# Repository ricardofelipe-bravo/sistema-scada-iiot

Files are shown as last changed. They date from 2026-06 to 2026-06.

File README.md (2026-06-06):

# Sistema SCADA con Nodo Edge IIoT — Monitor de Variables Eléctricas

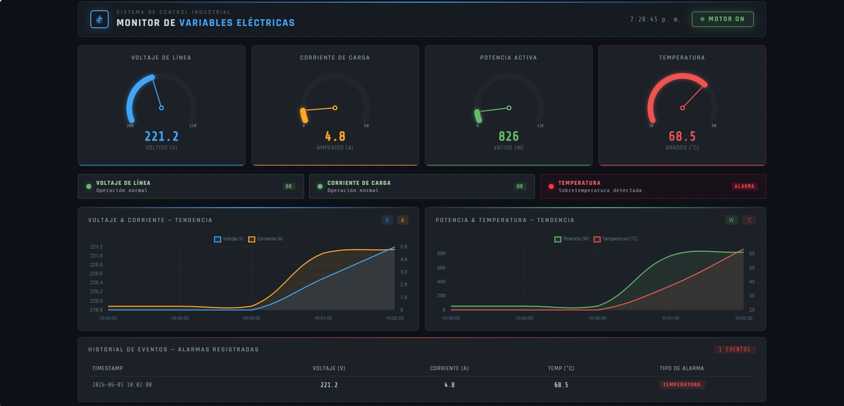
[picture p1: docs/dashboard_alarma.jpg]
Dashboard Alarma


Sistema de monitoreo industrial en tiempo real que integra un nodo Edge basado en **ESP32**, comunicación segura **MQTT/TLS**, protocolo industrial **Modbus TCP** y un dashboard **SCADA web** desarrollado con Python y Flask. Diseñado para supervisión de variables eléctricas en motores industriales con detección automática de alarmas y notificaciones por email.

---

## Arquitectura del Sistema

```
ESP32 (Nodo Edge)
  │  WiFi + Portal Cautivo
  │  MQTT/TLS — HiveMQ Cloud (puerto 8883)
  ▼
Python — monitor.py
  │  Suscriptor MQTT
  ├── SQLite (histórico de mediciones)
  ├── Alertas Email (SMTP — flanco ascendente)
  └── Flask — app.py
          │  API REST
          ▼
    Dashboard Web
    Chart.js — tiempo real
    Gauges + Gráficas + Historial de alarmas
```

---

## Características

- **Nodo Edge ESP32** con portal cautivo para configuración WiFi sin reprogramar, sincronización horaria NTP y LEDs indicadores de estado
- **Dos versiones de firmware** — producción con sensor PZEM-004T y simulación para pruebas sin hardware
- **Comunicación MQTT/TLS** sobre HiveMQ Cloud con publicación de JSON estructurado cada 2 segundos
- **Dashboard SCADA web** con gauges estilo velocímetro, gráficas de tendencia en tiempo real, panel de alarmas y historial de eventos
- **Base de datos SQLite** para almacenamiento histórico de mediciones
- **Sistema de alarmas** con detección por flanco ascendente y notificación automática por email
- **PCB diseñada en KiCad 8** para integración con sensor PZEM-004T
- Arquitectura preparada para conexión con **PLC vía Modbus TCP**

---

## Firmware ESP32 — Dos Versiones

### `nodo_edge_iiot_sensor.ino` — Producción (con PZEM-004T)
Versión para uso con hardware real. Lee voltaje, corriente, potencia activa, energía acumulada, frecuencia y factor de potencia directamente del sensor PZEM-004T. Detecta automáticamente si el sensor no responde.

### `nodo_edge_iiot_simulacion.ino` — Simulación (sin sensor)
Versión para pruebas del sistema completo sin hardware de medición. Simula un motor industrial 1HP / 220V con comportamiento realista — arranque, carga nominal, calentamiento gradual y generación de alarmas.

---

## Portal Cautivo — Configuración WiFi

El ESP32 incluye un portal cautivo que permite configurar la red WiFi sin necesidad de reprogramar el dispositivo.

### Cómo funciona

**Primera vez (sin credenciales guardadas):**

1. El ESP32 enciende y no encuentra red WiFi configurada
2. Crea automáticamente una red WiFi propia:
   - **Red:** `NodoEdge_Config`
   - **Contraseña:** `nodo1234`
3. Conéctate a esa red desde tu celular o computador
4. Se abre automáticamente una página de configuración en `192.168.4.1`
5. Selecciona tu red WiFi e ingresa la contraseña
6. El ESP32 guarda las credenciales y se conecta

**Siguiente encendido:**
- El ESP32 se conecta automáticamente sin mostrar el portal

**Si necesitas cambiar la red:**
- Mantén presionado el botón RESET por 10 segundos para borrar credenciales
- El portal cautivo se activa de nuevo

### Indicadores LED durante el portal
| LED | Estado | Significado |
|---|---|---|
| WiFi (GPIO23) | Parpadeo rápido | Portal cautivo activo |
| WiFi (GPIO23) | Fijo encendido | WiFi conectado |
| MQTT (GPIO22) | Fijo encendido | HiveMQ conectado |
| Alarma (GPIO21) | Fijo encendido | Variable fuera de rango |

---

## Conexión PZEM-004T al ESP32

```
PZEM-004T          ESP32 DevKit 38 pines
─────────          ──────────────────────
VCC (5V)    →      VIN  (pin 19)
GND         →      GND  (pin 14)
TX          →      GPIO16 / RX2  (pin 28)
RX          →      GPIO17 / TX2  (pin 29)
```

> **Importante:** El PZEM-004T trabaja con 220V en su lado de medición. Maneja las conexiones de alta tensión con precaución.

---

## Variables Monitoreadas

| Variable | Unidad | Rango normal | Umbral de alarma |
|---|---|---|---|
| Voltaje de línea | V | 200 – 240 | > 228 V |
| Corriente de carga | A | 0 – 6 | > 5 A |
| Potencia activa | W | calculada | — |
| Factor de potencia | — | 0.75 – 0.95 | — |
| Temperatura | °C | 25 – 65 | > 65 °C |
| Energía acumulada | kWh | — | — |
| Frecuencia | Hz | 59 – 61 | — |

---

## Stack Tecnológico

### Firmware ESP32
| Librería | Autor | Función |
|---|---|---|
| WiFiManager | tzapu | Portal cautivo para configuración WiFi |
| PubSubClient | Nick O'Leary | Cliente MQTT |
| ArduinoJson | Benoit Blanchon | Serialización JSON |
| PZEM004Tv30 | Jakub Mandula | Lectura sensor PZEM-004T |
| WiFiClientSecure | ESP32 built-in | Conexión TLS/SSL |
| time.h | ESP32 built-in | Sincronización NTP |

### Backend Python
| Librería | Función |
|---|---|
| paho-mqtt | Suscripción al broker MQTT |
| flask | Servidor web y API REST |
| sqlite3 | Base de datos histórica |
| smtplib | Envío de alertas por email |

### Frontend
| Tecnología | Función |
|---|---|
| Chart.js | Gráficas de tendencia en tiempo real |
| HTML/CSS/JS | Dashboard SCADA responsivo |
| SVG | Gauges estilo velocímetro animados |

---

## Estructura del Proyecto

```
sistema-scada-iiot/
│
├── monitor.py                          # Suscriptor MQTT + SQLite + alertas email
├── app.py                              # Servidor Flask + API REST
├── .gitignore
│
├── templates/
│   └── index.html                      # Dashboard SCADA
│
├── static/
│   └── chart.js                        # Librería Chart.js (local)
│
├── nodo_edge_iiot.ino/
│   ├── nodo_edge_iiot_sensor.ino       # Firmware producción (PZEM-004T)
│   └── nodo_edge_iiot_simulacion.ino   # Firmware simulación (pruebas)
│
├── pcb/
│   ├── nodo edge IIot.kicad_sch        # Esquemático
│   ├── nodo edge IIot.kicad_pcb        # Layout PCB
│   └── nodo edge IIot.kicad_pro        # Proyecto KiCad
│
└── docs/
    ├── dashboard_motor_off.jpg         # Dashboard — motor apagado
    ├── dashboard_motor_on.jpg          # Dashboard — motor encendido
    └── dashboard_alarma.jpg            # Dashboard — alarma activa
```

---

## Cómo Correr el Proyecto

### Requisitos Python
```bash
pip install flask paho-mqtt
```

### 1. Iniciar el monitor MQTT
```bash
python monitor.py
```

### 2. Iniciar el servidor web
```bash
python app.py
```

### 3. Abrir el dashboard
```
http://127.0.0.1:5000
```

### 4. Publicar datos de prueba desde HiveMQ
Topic: `industrial/motor/variables`

**Motor apagado:**
```json
{"voltaje":219.8,"corriente":0.3,"potencia":55.2,"factor_potencia":0.92,"temperatura":25.0,"estado_motor":0,"timestamp":"2026-06-05 10:00:00"}
```

**Motor encendido:**
```json
{"voltaje":220.5,"corriente":4.5,"potencia":773.6,"factor_potencia":0.78,"temperatura":42.3,"estado_motor":1,"timestamp":"2026-06-05 10:01:00"}
```

**Alarma de temperatura:**
```json
{"voltaje":221.2,"corriente":4.8,"potencia":826.4,"factor_potencia":0.78,"temperatura":68.5,"estado_motor":1,"timestamp":"2026-06-05 10:02:00"}
```

---

---

## Configuración HiveMQ Cloud

HiveMQ Cloud es el broker MQTT que recibe los datos del ESP32 y los entrega a Python.

### Crear cuenta y cluster gratuito

1. Ve a [console.hivemq.cloud](https://console.hivemq.cloud)
2. Crea una cuenta gratuita
3. Click en **"Create new cluster"** → selecciona plan **Free**
4. Elige la región más cercana (US East o EU)
5. Espera que el cluster esté activo (~1 minuto)

### Crear credenciales de acceso

1. Dentro del cluster ve a **"Access Management"**
2. Click en **"Add new credentials"**
3. Crea un usuario y contraseña — guárdalos
4. Permiso: **Publicar y Suscribirse**
5. Click en **Guardar**

### Datos de conexión

Una vez creado el cluster, en la página principal encuentras:

| Parámetro | Dónde encontrarlo | Ejemplo |
|---|---|---|
| Host | Página principal del cluster | `xxxx.s1.eu.hivemq.cloud` |
| Puerto TLS | Siempre es 8883 | `8883` |
| Usuario | Access Management | el que creaste |
| Contraseña | Access Management | la que creaste |

### Actualizar credenciales en el firmware

En el archivo `.ino` busca estas líneas y reemplaza con tus datos:

```cpp
const char* MQTT_HOST = "TU_HOST.s1.eu.hivemq.cloud";
const char* MQTT_USER = "tu_usuario";
const char* MQTT_PASS = "tu_contraseña";
```

### Actualizar credenciales en Python

En `monitor.py` busca:

```python
MQTT_HOST = "TU_HOST.s1.eu.hivemq.cloud"
MQTT_USER = "tu_usuario"
MQTT_PASS = "tu_contraseña"
```

### Probar la conexión desde el cliente web

1. En tu consola HiveMQ ve a la pestaña **"Cliente web"**
2. Conecta con tus credenciales
3. Publica un JSON al topic `industrial/motor/variables`
4. Verifica que `monitor.py` lo recibe en la terminal

---

## PCB — Nodo Edge IIoT

Diseñada en **KiCad 8** para montaje del nodo de medición de variables eléctricas.

### Componentes

| Componente | Referencia | Función |
|---|---|---|
| ESP32 DevKit 38 pines | U1 | Controlador principal |
| PZEM-004T | J1 | Sensor de variables eléctricas |
| LED verde | D1 | Indicador WiFi (GPIO23) |
| LED azul | D2 | Indicador MQTT (GPIO22) |
| LED rojo | D3 | Indicador Alarma (GPIO21) |
| Resistencias 330Ω | R1, R2, R3 | Limitación corriente LEDs |
| Condensador 100µF | C1 | Filtrado alimentación |
| Condensador 100nF | C2 | Desacople alta frecuencia |
| DC Jack 5V | J2 | Entrada de alimentación |

### Alimentación

```
Adaptador 5V DC
      │
   DC Jack
      │
   ESP32 VIN (pin 19) ──── PZEM-004T VCC
      │
   ESP32 interno 3.3V ──── lógica interna
```

### Archivos KiCad en carpeta `pcb/`

| Archivo | Contenido |
|---|---|
| `.kicad_sch` | Esquemático completo con conexiones |
| `.kicad_pcb` | Layout de la PCB con ruteo |
| `.kicad_pro` | Proyecto KiCad con configuración |

> Los archivos pueden abrirse directamente con **KiCad 8.0** disponible en [kicad.org](https://www.kicad.org)

## Capturas del Dashboard

### Motor apagado — operación normal
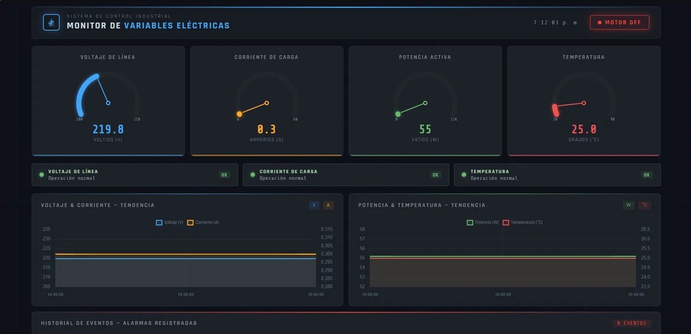
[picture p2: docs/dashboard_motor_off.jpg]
Motor OFF


### Motor encendido — carga nominal
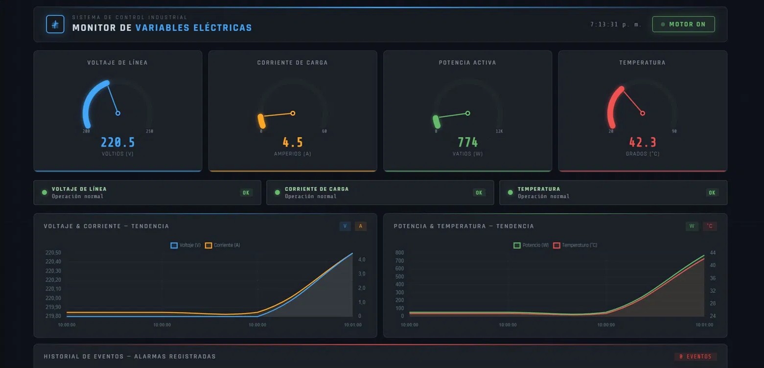
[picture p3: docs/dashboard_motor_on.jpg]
Motor ON


### Alarma activa — sobretemperatura
Alarma

---

## Autor

**Ricardo Felipe Bravo**  
Ingeniero Electrónico — Universidad de Nariño  
Orientado al sector eléctrico e industrial

📩 ricardofelipebravo12@gmail.com  
🔗 [LinkedIn](https://www.linkedin.com/in/ricardofelipe-bravo)

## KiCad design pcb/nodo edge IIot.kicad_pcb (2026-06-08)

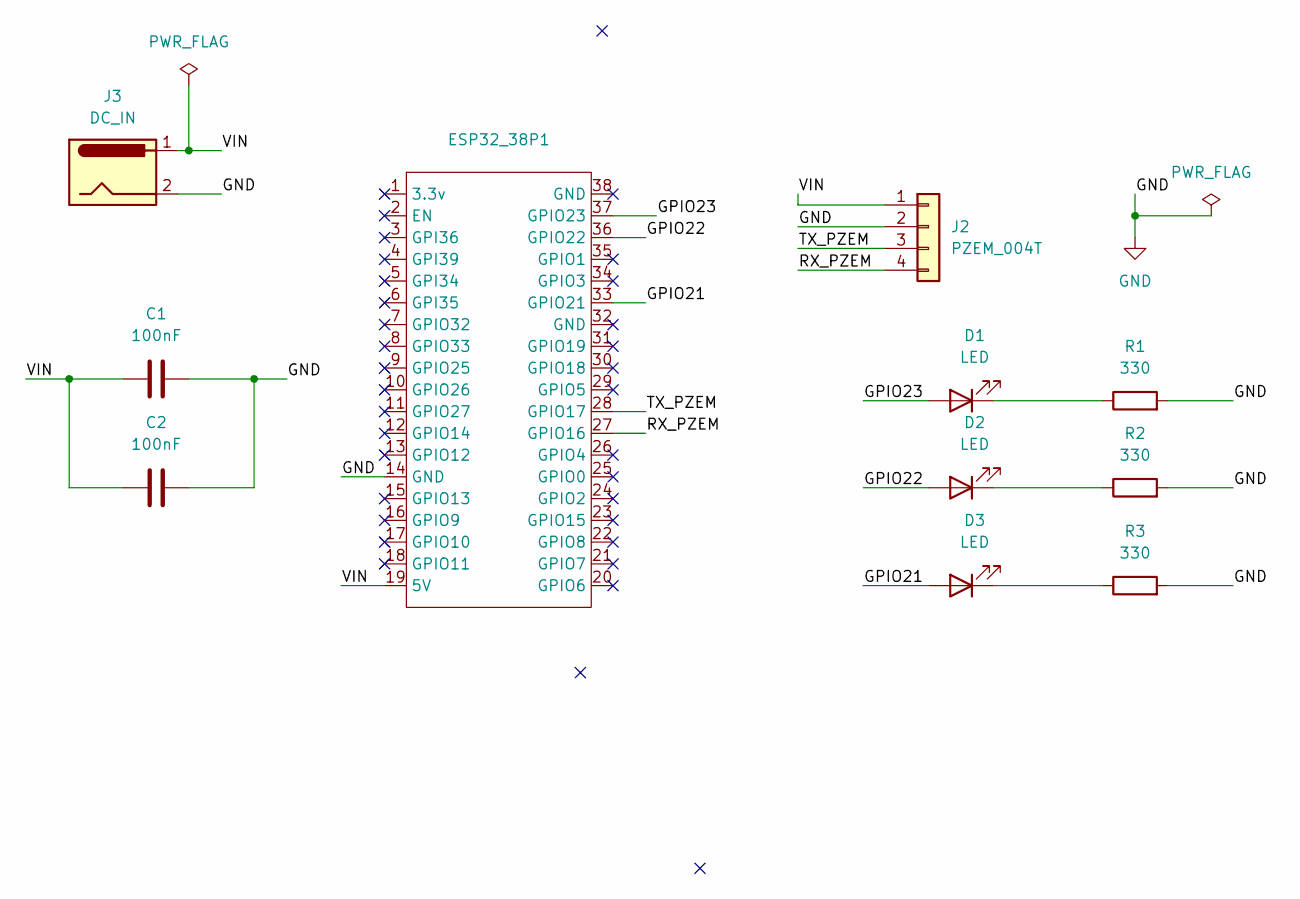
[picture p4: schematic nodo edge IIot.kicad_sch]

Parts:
C1, C2: 100nF; C_Disc_D5.0mm_W2.5mm_P5.00mm
D1, D2, D3: LED; LED_D3.0mm
ESP32_38P1: ESP32-38pin
J2: PZEM_004T; PinHeader_1x04_P2.54mm_Vertical
J3: DC_IN; BarrelJack_Horizontal
R1, R2, R3: 330; R_Axial_DIN0207_L6.3mm_D2.5mm_P7.62mm_Horizontal

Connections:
/GPIO21: D3.2 (A), ESP32_38P1.33 (GPIO21)
/GPIO22: D2.2 (A), ESP32_38P1.36 (GPIO22)
/GPIO23: D1.2 (A), ESP32_38P1.37 (GPIO23)
/RX_PZEM: ESP32_38P1.27 (GPIO16), J2.4
/TX_PZEM: ESP32_38P1.28 (GPIO17), J2.3
/VIN: C1.1, C2.1, ESP32_38P1.19 (5V), J2.1, J3.1
GND: C1.2, C2.2, ESP32_38P1.14 (GND), J2.2, J3.2, R1.2, R2.2, R3.2
unnamed: D1.1 (K), R1.1
unnamed: D2.1 (K), R2.1
unnamed: D3.1 (K), R3.1

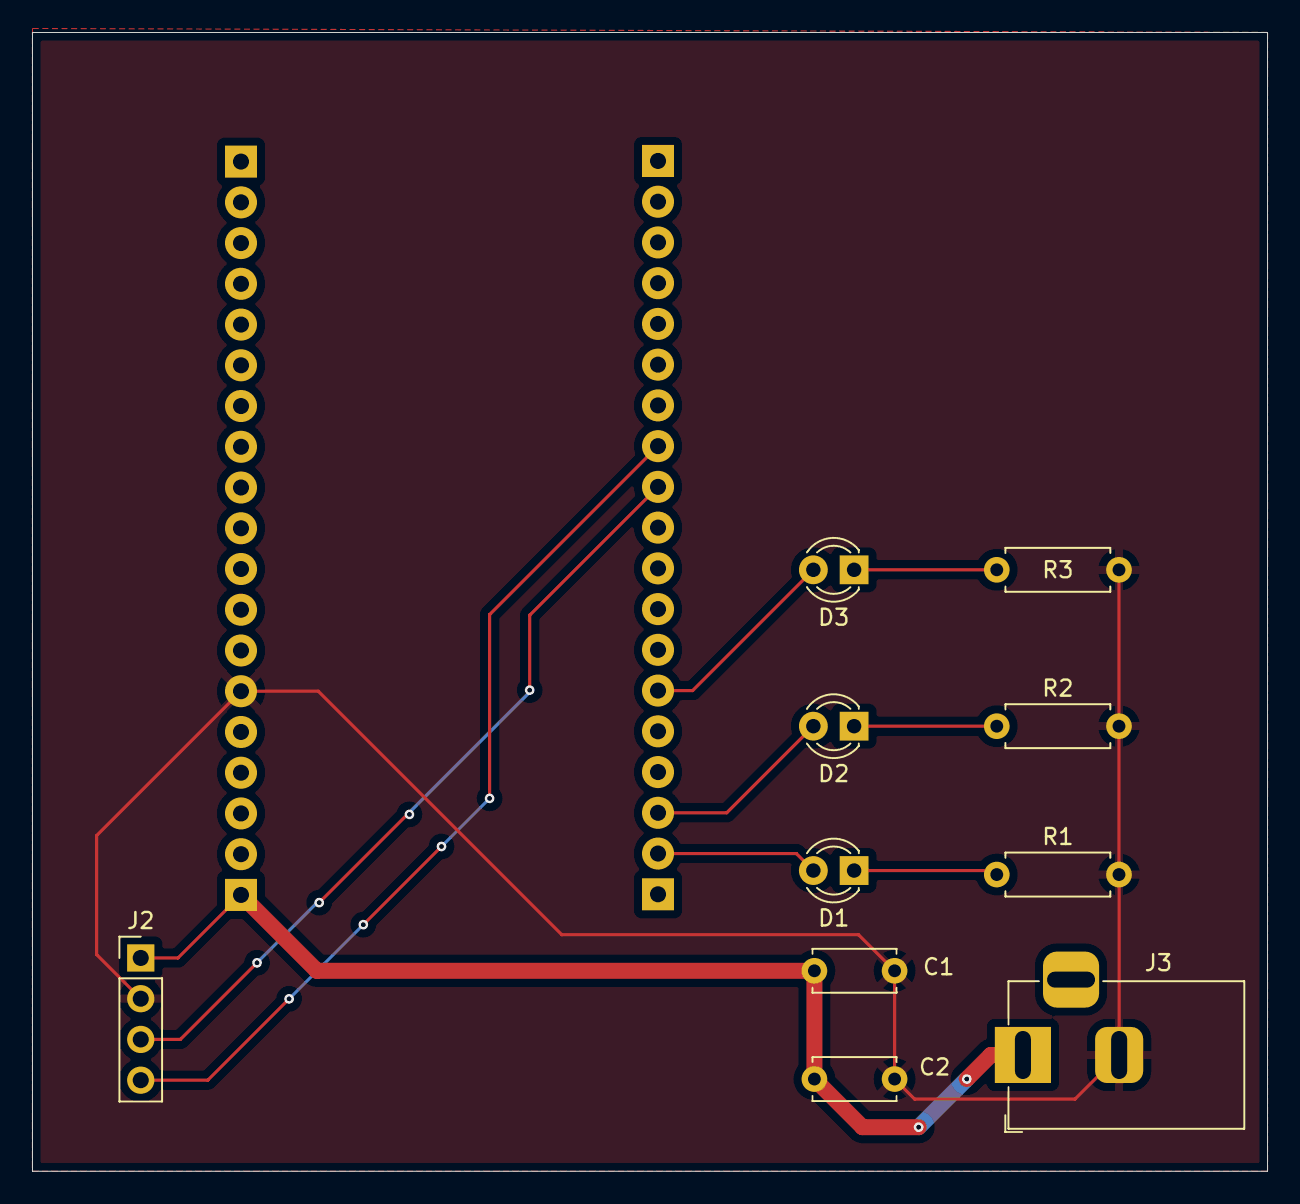
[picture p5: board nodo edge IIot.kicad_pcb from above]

Board: 2 copper layers, 77.0 x 71.0 mm, 11 parts (1 on the bottom side), 10 nets.

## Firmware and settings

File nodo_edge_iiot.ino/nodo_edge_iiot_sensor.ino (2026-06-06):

/*
 * ============================================================
 *  NODO EDGE IIoT — VERSIÓN PRODUCCIÓN (con sensor PZEM-004T)
 * ============================================================
 * Hardware requerido:
 *   - ESP32 DevKit 38 pines
 *   - Sensor PZEM-004T (conectado a GPIO16/GPIO17)
 *   - LEDs: WiFi (GPIO23), MQTT (GPIO22), Alarma (GPIO21)
 *
 * Librerías requeridas:
 *   - WiFiManager     (tzapu)
 *   - PubSubClient    (Nick O'Leary)
 *   - ArduinoJson     (Benoit Blanchon)
 *   - PZEM004Tv30     (Jakub Mandula)
 *
 * Conexión PZEM-004T:
 *   PZEM TX  →  ESP32 GPIO16 (RX2)
 *   PZEM RX  →  ESP32 GPIO17 (TX2)
 *   PZEM VCC →  ESP32 VIN (5V)
 *   PZEM GND →  ESP32 GND
 *
 * Procesamiento local (Edge):
 *   - Filtrado de lecturas inválidas del sensor
 *   - Detección local de alarmas sin depender del servidor
 *   - Buffer circular de 20 muestras cuando no hay conexión MQTT
 *   - Reenvío automático del buffer al reconectar
 *   - LED de alarma activado localmente sin necesidad de red
 * ============================================================
 */

#include <WiFi.h>
#include <WiFiClientSecure.h>
#include <PubSubClient.h>
#include <ArduinoJson.h>
#include <WiFiManager.h>
#include <PZEM004Tv30.h>
#include <time.h>

// ─── HiveMQ Cloud ───────────────────────────────────────────
const char* MQTT_HOST      = "512b0b58cfc548398f97951eeb91530e.s1.eu.hivemq.cloud";
const int   MQTT_PORT      = 8883;
const char* MQTT_USER      = "edgecloud";
const char* MQTT_PASS      = "Esp32cloud";
const char* MQTT_TOPIC     = "industrial/motor/variables";
const char* MQTT_CLIENT_ID = "ESP32_Motor_01";

// ─── NTP ────────────────────────────────────────────────────
const char* NTP_SERVER = "pool.ntp.org";
const long  GMT_OFFSET = -18000;  // Colombia UTC-5
const int   DST_OFFSET = 0;

// ─── LEDs ───────────────────────────────────────────────────
#define LED_WIFI   23
#define LED_MQTT   22
#define LED_ALARMA 21

// ─── PZEM-004T (Serial2: RX=16, TX=17) ─────────────────────
PZEM004Tv30 pzem(Serial2, 16, 17);

WiFiClientSecure espClient;
PubSubClient     mqttClient(espClient);

// ─── Buffer local (Edge processing) ────────────────────────
// Almacena hasta 20 muestras cuando no hay conexión MQTT
#define BUFFER_SIZE 20
String bufferLocal[BUFFER_SIZE];
int    bufferHead  = 0;
int    bufferCount = 0;

void guardarEnBuffer(const char* payload) {
    bufferLocal[bufferHead] = String(payload);
    bufferHead = (bufferHead + 1) % BUFFER_SIZE;
    if (bufferCount < BUFFER_SIZE) bufferCount++;
    Serial.printf("[BUFFER] %d/%d muestras almacenadas localmente\n",
                  bufferCount, BUFFER_SIZE);
}

void vaciarBuffer() {
    if (bufferCount == 0) return;
    int inicio = (bufferHead - bufferCount + BUFFER_SIZE) % BUFFER_SIZE;
    Serial.printf("[BUFFER] Enviando %d muestras almacenadas...\n", bufferCount);
    for (int i = 0; i < bufferCount; i++) {
        int idx = (inicio + i) % BUFFER_SIZE;
        mqttClient.publish(MQTT_TOPIC, bufferLocal[idx].c_str());
        delay(100);
    }
    bufferCount = 0;
    bufferHead  = 0;
    Serial.println("[BUFFER] Buffer vaciado correctamente");
}

// ─── Filtro de lecturas (Edge processing) ───────────────────
// Promedio móvil de las últimas 3 lecturas válidas
#define FILTRO_N 3
float filtroVoltaje[FILTRO_N]   = {220, 220, 220};
float filtroCorriente[FILTRO_N] = {0, 0, 0};
int   filtroIdx = 0;

float aplicarFiltro(float* arr, float nuevo) {
    arr[filtroIdx % FILTRO_N] = nuevo;
    float suma = 0;
    for (int i = 0; i < FILTRO_N; i++) suma += arr[i];
    return suma / FILTRO_N;
}

// ─── Portal Cautivo ─────────────────────────────────────────
void iniciarPortalCautivo() {
    WiFiManager wifiManager;

    wifiManager.setAPCallback([](WiFiManager* mgr) {
        Serial.println("==============================");
        Serial.println("  PORTAL DE CONFIGURACION");
        Serial.println("  Red WiFi:   NodoEdge_Config");
        Serial.println("  Contrasena: nodo1234");
        Serial.println("  IP portal:  192.168.4.1");
        Serial.println("==============================");
        for (int i = 0; i < 20; i++) {
            digitalWrite(LED_WIFI, HIGH); delay(100);
            digitalWrite(LED_WIFI, LOW);  delay(100);
        }
    });

    wifiManager.setConfigPortalTimeout(180);

    if (!wifiManager.autoConnect("NodoEdge_Config", "nodo1234")) {
        Serial.println("Timeout portal — reiniciando...");
        delay(3000);
        ESP.restart();
    }

    digitalWrite(LED_WIFI, HIGH);
    Serial.println("WiFi conectado: " + WiFi.localIP().toString());
}

// ─── NTP ────────────────────────────────────────────────────
void sincronizarNTP() {
    configTime(GMT_OFFSET, DST_OFFSET, NTP_SERVER);
    Serial.print("Sincronizando NTP");
    struct tm timeinfo;
    while (!getLocalTime(&timeinfo)) {
        Serial.print(".");
        delay(500);
    }
    char buf[30];
    strftime(buf, sizeof(buf), "%Y-%m-%d %H:%M:%S", &timeinfo);
    Serial.println("\nNTP OK: " + String(buf));
}

// ─── MQTT ───────────────────────────────────────────────────
void conectarMQTT() {
    espClient.setInsecure();
    mqttClient.setServer(MQTT_HOST, MQTT_PORT);
    mqttClient.setBufferSize(512);

    int intentos = 0;
    while (!mqttClient.connected() && intentos < 5) {
        Serial.print("Conectando a HiveMQ...");
        if (mqttClient.connect(MQTT_CLIENT_ID, MQTT_USER, MQTT_PASS)) {
            Serial.println("Conectado");
            digitalWrite(LED_MQTT, HIGH);
            vaciarBuffer(); // reenviar muestras almacenadas
        } else {
            Serial.printf("Error: %d — reintento %d/5\n",
                          mqttClient.state(), ++intentos);
            digitalWrite(LED_MQTT, LOW);
            delay(3000);
        }
    }
}

// ─── Leer PZEM, filtrar y publicar ──────────────────────────
void leerFiltrarYPublicar() {
    // Leer sensor
    float voltajeBruto   = pzem.voltage();
    float corrienteBruta = pzem.current();
    float potencia       = pzem.power();
    float energia        = pzem.energy();
    float frecuencia     = pzem.frequency();
    float factorPotencia = pzem.pf();

    // Verificar lectura válida — procesamiento local
    if (isnan(voltajeBruto) || isnan(corrienteBruta)) {
        Serial.println("[ERROR] Sensor no responde — verifica conexiones PZEM-004T");
        digitalWrite(LED_ALARMA, HIGH);
        delay(200);
        digitalWrite(LED_ALARMA, LOW);
        return;
    }

    // Aplicar filtro promedio móvil — reduce ruido del sensor
    float voltaje   = aplicarFiltro(filtroVoltaje,   voltajeBruto);
    float corriente = aplicarFiltro(filtroCorriente, corrienteBruta);
    filtroIdx++;

    // Detección local de alarmas — sin depender del servidor
    bool alarmaVoltaje   = (voltaje   > 228.0);
    bool alarmaCorreinte = (corriente > 5.0);
    bool alarma          = alarmaVoltaje || alarmaCorreinte;
    digitalWrite(LED_ALARMA, alarma ? HIGH : LOW);

    if (alarma) {
        Serial.printf("[ALARMA LOCAL] V=%.1f I=%.2f\n", voltaje, corriente);
    }

    // Timestamp NTP
    struct tm timeinfo;
    char timeStr[20] = "sin_sync";
    if (getLocalTime(&timeinfo)) {
        strftime(timeStr, sizeof(timeStr), "%Y-%m-%d %H:%M:%S", &timeinfo);
    }

    // Construir JSON
    StaticJsonDocument<256> doc;
    doc["voltaje"]         = round(voltaje       * 10)   / 10.0;
    doc["corriente"]       = round(corriente      * 100)  / 100.0;
    doc["potencia"]        = round(potencia       * 10)   / 10.0;
    doc["energia"]         = round(energia        * 100)  / 100.0;
    doc["frecuencia"]      = round(frecuencia     * 10)   / 10.0;
    doc["factor_potencia"] = round(factorPotencia * 1000) / 1000.0;
    doc["estado_motor"]    = (corriente > 0.5) ? 1 : 0;
    doc["timestamp"]       = timeStr;

    char buffer[256];
    serializeJson(doc, buffer);

    // Publicar o guardar en buffer local
    if (mqttClient.connected()) {
        mqttClient.publish(MQTT_TOPIC, buffer);
        Serial.println(buffer);
    } else {
        guardarEnBuffer(buffer);
    }
}

// ─── Setup ──────────────────────────────────────────────────
void setup() {
    Serial.begin(115200);

    pinMode(LED_WIFI,   OUTPUT);
    pinMode(LED_MQTT,   OUTPUT);
    pinMode(LED_ALARMA, OUTPUT);
    digitalWrite(LED_WIFI,   LOW);
    digitalWrite(LED_MQTT,   LOW);
    digitalWrite(LED_ALARMA, LOW);

    Serial.println("\n============================");
    Serial.println("  NODO EDGE IIoT — PRODUCCION");
    Serial.println("  Sensor: PZEM-004T");
    Serial.println("  Edge: filtro + buffer local");
    Serial.println("============================");

    iniciarPortalCautivo();
    sincronizarNTP();
    conectarMQTT();
}

// ─── Loop ───────────────────────────────────────────────────
void loop() {
    if (WiFi.status() != WL_CONNECTED) {
        digitalWrite(LED_WIFI, LOW);
        iniciarPortalCautivo();
    }
    if (!mqttClient.connected()) {
        digitalWrite(LED_MQTT, LOW);
        conectarMQTT();
    }
    mqttClient.loop();
    leerFiltrarYPublicar();
    delay(2000);
}

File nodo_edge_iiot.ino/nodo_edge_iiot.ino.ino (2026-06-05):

#include <WiFi.h>
#include <WiFiClientSecure.h>
#include <PubSubClient.h>
#include <ArduinoJson.h>
#include <time.h>
#include <WiFiManager.h>

// HiveMQ Cloud
const char* MQTT_HOST      = "512b0b58cfc548398f97951eeb91530e.s1.eu.hivemq.cloud";
const int   MQTT_PORT      = 8883;
const char* MQTT_USER      = "edgecloud";
const char* MQTT_PASS      = "Esp32cloud";
const char* MQTT_TOPIC     = "industrial/motor/variables";
const char* MQTT_CLIENT_ID = "ESP32_Motor_01";

// NTP
const char* NTP_SERVER = "pool.ntp.org";
const long  GMT_OFFSET = -18000;
const int   DST_OFFSET = 0;

// LEDs
#define LED_WIFI   23
#define LED_MQTT   22
#define LED_ALARMA 21

WiFiClientSecure espClient;
PubSubClient mqttClient(espClient);

bool  estado_motor = false;
float temperatura  = 25.0;
int   ciclo        = 0;

// ─── Portal Cautivo ─────────────────────────────────────
void iniciarPortalCautivo() {
    WiFiManager wifiManager;
    
    // Personalizar página del portal
    wifiManager.setAPCallback([](WiFiManager* mgr) {
        Serial.println("Portal cautivo activo");
        Serial.println("Conectate a: NodoEdge_Config");
        Serial.println("IP: 192.168.4.1");
        // Parpadeo rápido LED WiFi = portal activo
        for (int i = 0; i < 10; i++) {
            digitalWrite(LED_WIFI, HIGH);
            delay(100);
            digitalWrite(LED_WIFI, LOW);
            delay(100);
        }
    });

    // Timeout 3 minutos para configurar
    wifiManager.setConfigPortalTimeout(180);

    // Intenta conectar con credenciales guardadas
    // Si falla, levanta portal con nombre "NodoEdge_Config"
    if (!wifiManager.autoConnect("NodoEdge_Config", "nodo1234")) {
        Serial.println("Timeout portal cautivo — reiniciando");
        delay(3000);
        ESP.restart();
    }

    Serial.println("WiFi conectado via portal: " + WiFi.localIP().toString());
    digitalWrite(LED_WIFI, HIGH);
}

// ─── NTP ────────────────────────────────────────────────
void sincronizarNTP() {
    configTime(GMT_OFFSET, DST_OFFSET, NTP_SERVER);
    Serial.print("Sincronizando NTP");
    struct tm timeinfo;
    while (!getLocalTime(&timeinfo)) {
        Serial.print(".");
        delay(500);
    }
    char buf[30];
    strftime(buf, sizeof(buf), "%Y-%m-%d %H:%M:%S", &timeinfo);
    Serial.println("\nNTP sincronizado: " + String(buf));
}

// ─── MQTT ───────────────────────────────────────────────
void conectarMQTT() {
    espClient.setInsecure();
    mqttClient.setServer(MQTT_HOST, MQTT_PORT);
    mqttClient.setBufferSize(512);

    while (!mqttClient.connected()) {
        Serial.print("Conectando a HiveMQ...");
        if (mqttClient.connect(MQTT_CLIENT_ID, MQTT_USER, MQTT_PASS)) {
            Serial.println("Conectado");
            digitalWrite(LED_MQTT, HIGH);
        } else {
            Serial.print("Error: ");
            Serial.println(mqttClient.state());
            digitalWrite(LED_MQTT, LOW);
            delay(3000);
        }
    }
}

// ─── Publicar variables ─────────────────────────────────
void publicarVariables() {
    ciclo++;

    if (ciclo % 60 == 0) {
        estado_motor = !estado_motor;
        Serial.println(estado_motor ? ">>> Motor ON <<<" : ">>> Motor OFF <<<");
    }

    float voltaje = 220.0 + random(-30, 30) / 10.0;
    float corriente, factor_potencia;

    if (estado_motor) {
        corriente       = 4.5  + random(-10, 10)  / 100.0;
        factor_potencia = 0.78 + random(-5,  5)   / 1000.0;
        temperatura     = min(80.0f, temperatura + random(2, 5) / 10.0f);
        digitalWrite(LED_ALARMA, temperatura > 65 ? HIGH : LOW);
    } else {
        corriente       = 0.3  + random(-5, 5)    / 100.0;
        factor_potencia = 0.92 + random(-3, 3)    / 1000.0;
        temperatura     = max(25.0f, temperatura - random(1, 3) / 10.0f);
        digitalWrite(LED_ALARMA, LOW);
    }

    float potencia = voltaje * corriente * factor_potencia;

    struct tm timeinfo;
    char timeStr[20] = "sin_sync";
    if (getLocalTime(&timeinfo)) {
        strftime(timeStr, sizeof(timeStr), "%Y-%m-%d %H:%M:%S", &timeinfo);
    }

    StaticJsonDocument<256> doc;
    doc["voltaje"]         = round(voltaje         * 10)   / 10.0;
    doc["corriente"]       = round(corriente        * 100)  / 100.0;
    doc["potencia"]        = round(potencia         * 10)   / 10.0;
    doc["factor_potencia"] = round(factor_potencia  * 1000) / 1000.0;
    doc["temperatura"]     = round(temperatura      * 10)   / 10.0;
    doc["estado_motor"]    = estado_motor ? 1 : 0;
    doc["timestamp"]       = timeStr;

    char buffer[256];
    serializeJson(doc, buffer);
    mqttClient.publish(MQTT_TOPIC, buffer);
    Serial.println(buffer);
}

// ─── Setup ──────────────────────────────────────────────
void setup() {
    Serial.begin(115200);
    randomSeed(analogRead(0));

    pinMode(LED_WIFI,   OUTPUT);
    pinMode(LED_MQTT,   OUTPUT);
    pinMode(LED_ALARMA, OUTPUT);

    digitalWrite(LED_WIFI,   LOW);
    digitalWrite(LED_MQTT,   LOW);
    digitalWrite(LED_ALARMA, LOW);

    iniciarPortalCautivo();  // WiFi con portal cautivo
    sincronizarNTP();
    conectarMQTT();
}

// ─── Loop ───────────────────────────────────────────────
void loop() {
    if (WiFi.status() != WL_CONNECTED) {
        digitalWrite(LED_WIFI, LOW);
        iniciarPortalCautivo();
    }
    if (!mqttClient.connected()) {
        digitalWrite(LED_MQTT, LOW);
        conectarMQTT();
    }
    mqttClient.loop();
    publicarVariables();
    delay(2000);
}

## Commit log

2026-06-05 Initial commit: Sistema SCADA IoT - monitor MQTT, dashboard Flask, firmware ESP32
2026-06-06 Add dashboard, PCB files, firmware, docs and project structure
    [nodo edge IIot.kicad_pcb, nodo edge IIot.kicad_sch]
2026-06-06 Update README: portal cautivo, firmware versions, PZEM-004T wiring
2026-06-06 Update README: HiveMQ setup guide and PCB components detail
2026-06-06 Add edge processing: local buffer, moving average filter, local alarm detection
2026-06-08 Update PCB design
    [nodo edge IIot.kicad_pcb, nodo edge IIot.kicad_sch]
